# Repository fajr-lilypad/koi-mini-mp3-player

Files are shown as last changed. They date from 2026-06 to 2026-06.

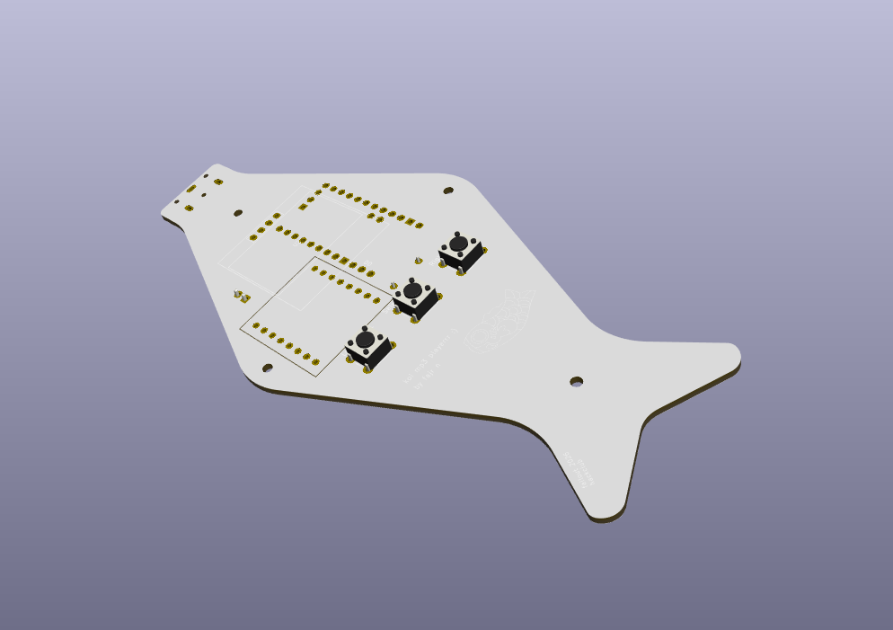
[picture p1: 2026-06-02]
PCB/ScreenshotPCB_3DViewer_SideB.png

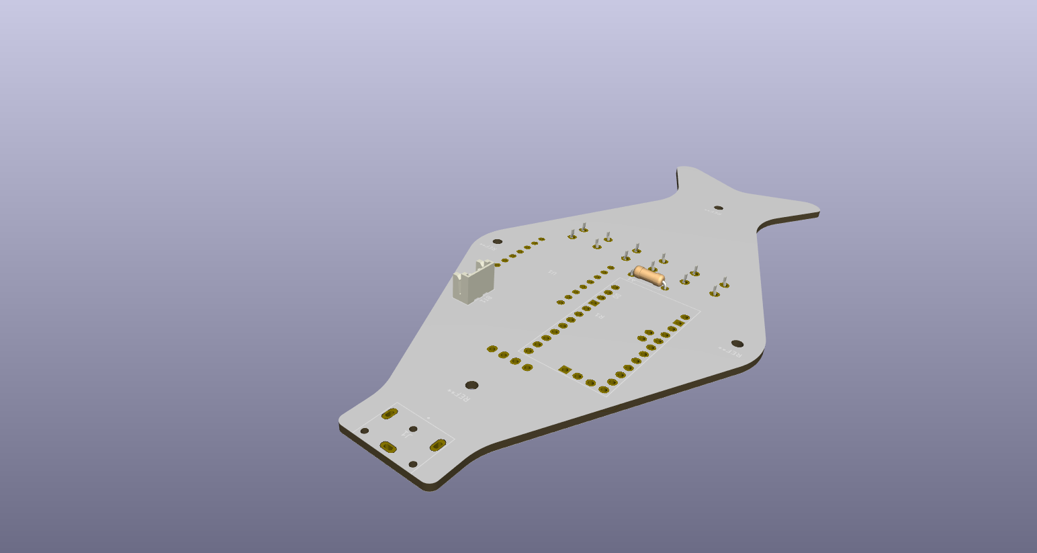
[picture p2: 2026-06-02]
PCB/PCBScreenshot_3DViewer.png

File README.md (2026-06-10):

# Koi Mini Mp3 Player!
A friendly fish shaped Mp3 player, that sings a tune to cheer you up :)



I came up with this idea when I came across creaters making projects that incorporated audio, and since I don't have as much experience with electrical projects, I thought this would be a fun and educational endeavor. When thinking over what cute designs and shapes I could make this, I became inspired by the friendly koi currency mascot used by hackclub's **fallout** program! I made this project because I wanted to learn more about complex electronics projects, as well as creating something practical that I can use day to day, and I listen to music all the time! And thus, here we are. This will be a helpful and cute tool for listening to tunes on the go, especially when I dont have access to spotify at school hahahaha (i'm **not** crying) (｡T ω T｡)

Some special things I did include making a more complex pcb than I have ever worked with before, along with not following a guided electronics project, so I kinda had to be more independent with troubleshooting and just making decsiions about my own project. In order to use this device, navigate through with a simple screen display to play songs stored on a micro sd card, along using right, left, and select buttons! It very simple to use and assemble. 

# CAD ScreenShots



<table>
  <tr>
    <td>
    
    </td>
    <td>
      
    </td>
    <td>
      
    </td>
  </tr>
</table>

CAD Notes:
- Arduino model in CAD does not match up with footrpint or irl, trust the footprint. it was just the best 3d model I could find.
- This CAD took surprisingly long! It was difficult for me to create a case that fufilled all my criteria, including space, aesthetics, and easy access to the pcb for simple troubleshooting. I ended up going with this design, but not after making several rough drafts of potential cases. I'm happy with this one, as it includes snap fit joints, a hole for the headphone jack, and is overall super cute :)
- The most difficult parts of this was the parts that nobody notices, mounting holes lol. took a while to align, but I'm sure most people are more efficient at cad than i am!

# PCB ScreenShots

<table>
  <tr>
    <td rowspan="2">
      
    </td>
    <td>
      
    </td>
  </tr>
  <tr>
    <td>
      
    </td>
  </tr>
</table>

PCB Notes:
- The PCB took me a **while**. It took 6 versions to come up with the final draft. The biggest difficulty was deciding a layout that would be easy to work with and troubleshoot, along with research into which components I should use. I had to learn how to do a lot of new things in KiCad, including making my own symbols!
- For structure, I created a blank PCB with the same shape attached to the bottom of the real pcb with brass standoffs. I found in my research that this is common when creating mp3 players, along with custom PCBs in general. After running into trouble with mounting, I scrapped that idea. Now, the there is just one pcb secured with standoffs.

## Schematic ScreenShot



# Zine !!



# Build Guide

Assembly for this Fish MP3 Player isn't too complicated. To start off, once components have arrived, be sure that your code is ready. When assembling components, I plan on starting out with a breadboard to test firmware before soldering, and be sure to secure the bottom blank pcb with standoffs. In the meantime, get the 3d printer started on the case top, bottom, and fins! The snap fit joints should make the case easy to work with, so it isnt hard to access the pcb.

## Firmware

I customized code for the display from Pcbcupid soundpod and used a butmap converter to display the images! Download whatever songs you'd like to be played on a micro sd card, and program to navigate through the files with the Pcbcupid reference mentioned earlier.

## BOM

| Item | Purpose | Price | Source | Link |
|---|---|---|---|---|
| Arduino Pro Mini | Microcontroller | $1.66 | AliExpress | https://www.aliexpress.us/item/3256809225264759.html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.. |
| DFPlayer Mini | Audio Module | $0.73 | AliExpress | https://www.aliexpress.us/item/3256806817772564.html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 |
| 1.3 in OLED | Display Screen | $0.99 | AliExpress | https://www.aliexpress.us/item/3256809997650807.html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 |
| TRS Female Headphone Jack | Audio output | $1.15 | DigiKey | https://shorturl.at/xDjAV | 
| 3.7 V Battery | Power | $4.18 | AliExpress | https://www.aliexpress.us/item/3256808681500642.html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 |
| 2 pin JST Battery Connector | Battery Connector | $3.90 | Aliexpress| https://shorturl.at/0xLe1 |
| Micro SD Card | Store songs | $1.13 | AliExpress | https://www.aliexpress.com/ssr/300000512/BundleDeals2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 |
| Micro Push Buttons | Inputs | $0.33 | Same Sky | https://www.sameskydevices.com/product/switches/tactile-switches/ts24-62-14-bl-250-smt-tr-67 |
| Custom Tactile Buttons | Comfort | $0 | 3D Printed |
| Custom Koi Case | Aesthetics | $0 | 3D Printed |
| Breadboard | testing | $0.55 | AliExpress | https://shorturl.at/7gDRe |
| Custom PCB | PCB | $5.30 | JLCPCB |
| Brass PCB standoffs | Supports structure | $0.99 | AliExpress | https://shorturl.at/dPENK |
| Soldering Iron | Assembly | $0 | Owned |
| 3D Printer | Case Manufacturing | $0 | Owned |
| Wired Headphones | Audio Output | $0 | Owned |
|  |  |  |  | **Subtotal: $20.91 USD**  |

## Notes and Acknowledgments
- Thank you to **Hackclub** and the **Fallout team** for making this project possible! It's because of you that I was inspired and able to make this project!
- Thank you to the user Digiicam for helpful inspo for wiring and components!
- Thank you to Pcbcupid for simple customizable firmware!

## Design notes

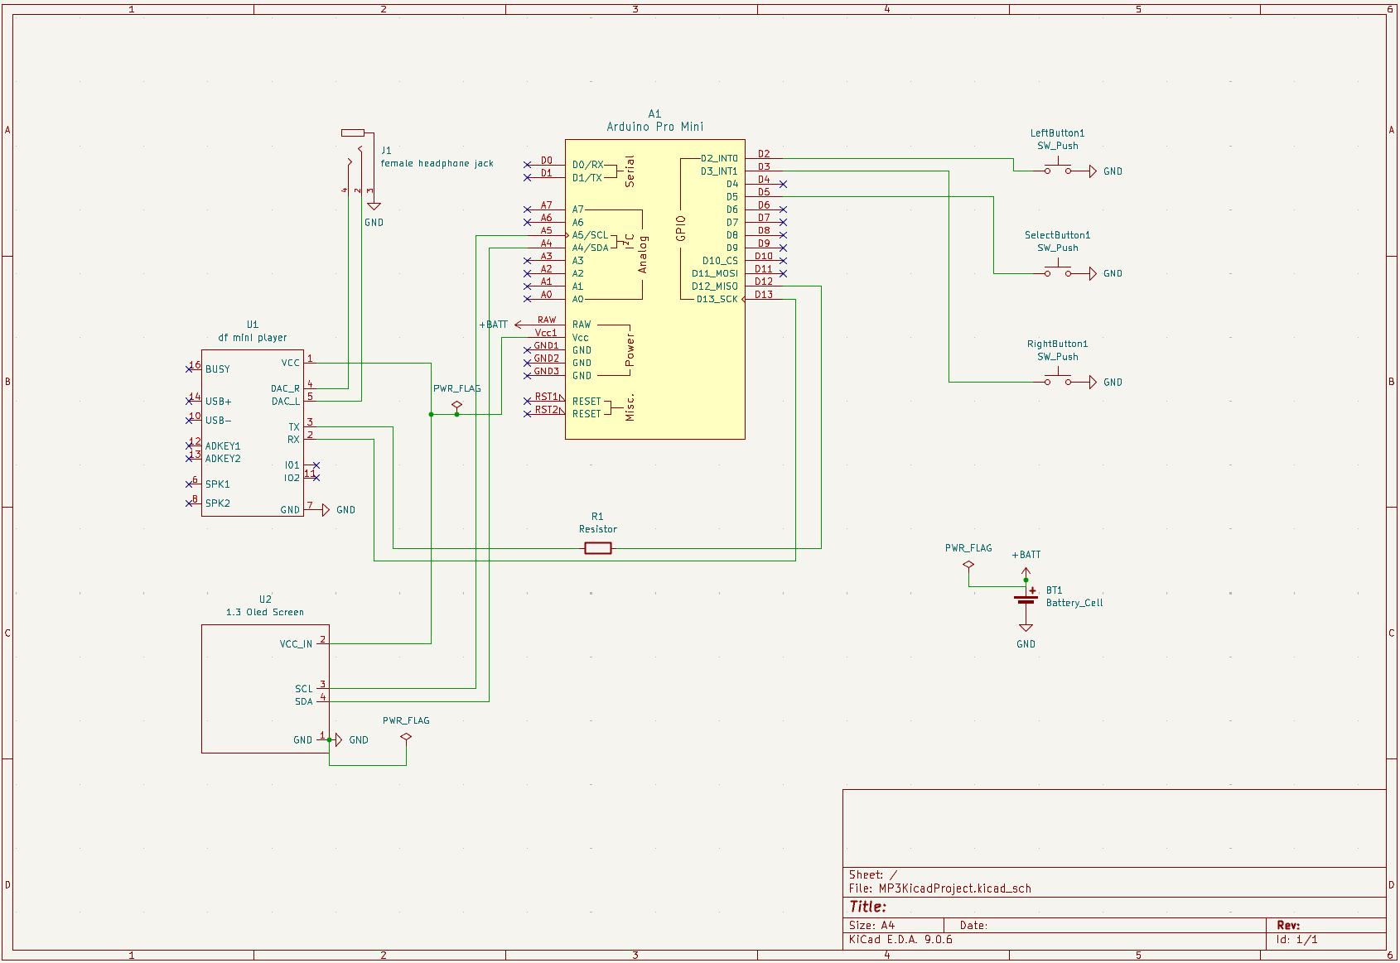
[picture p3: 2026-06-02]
Schematic/Screenshot 2026-06-01 223904.png

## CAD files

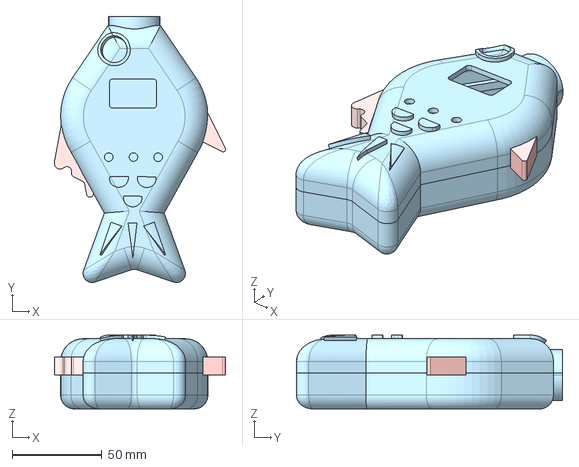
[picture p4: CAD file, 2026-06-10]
CAD/Case/Koi Case assembly.step
95.5 x 148.1 x 41.1 mm

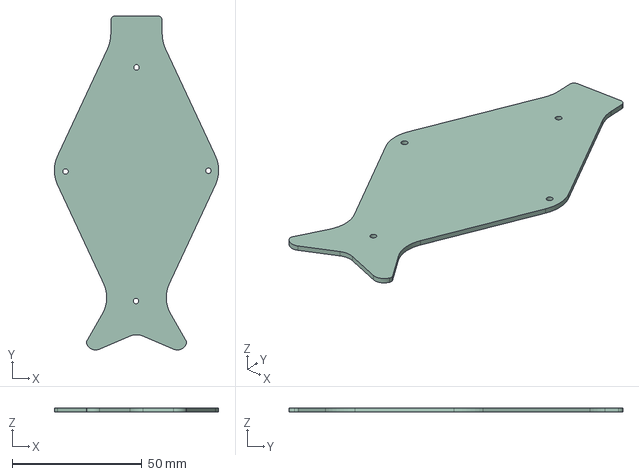
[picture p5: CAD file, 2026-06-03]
CAD/PCB Cad/Bottom Blank PCB.step
63.3 x 128.6 x 1.51 mm

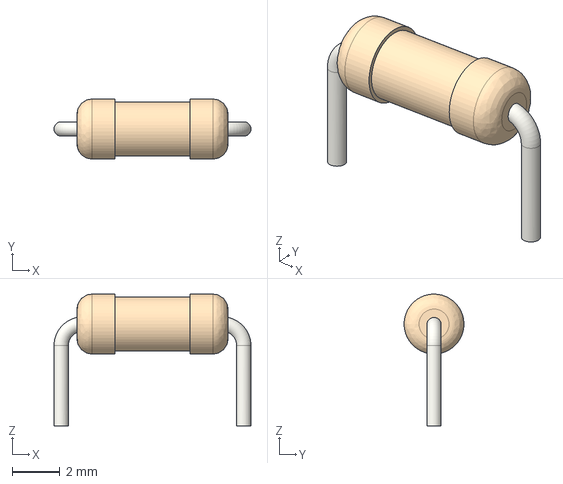
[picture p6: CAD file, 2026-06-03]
CAD/PCB Cad/Electronics/Resisitor.step
8.22 x 2.50 x 5.50 mm

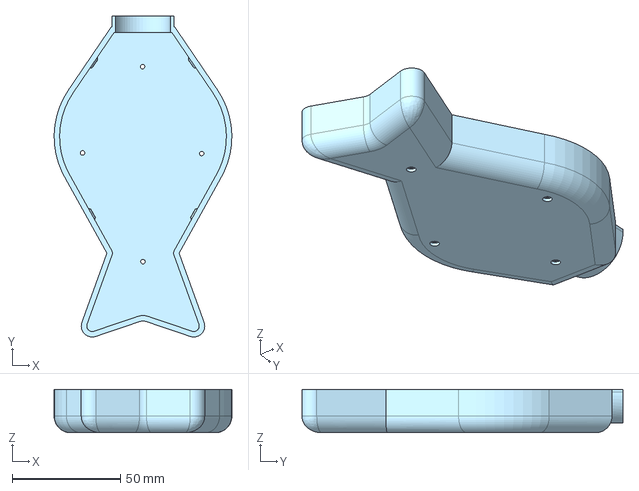
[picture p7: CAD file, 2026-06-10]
CAD/Case/koi case bottom.step
82.0 x 148.1 x 20.1 mm

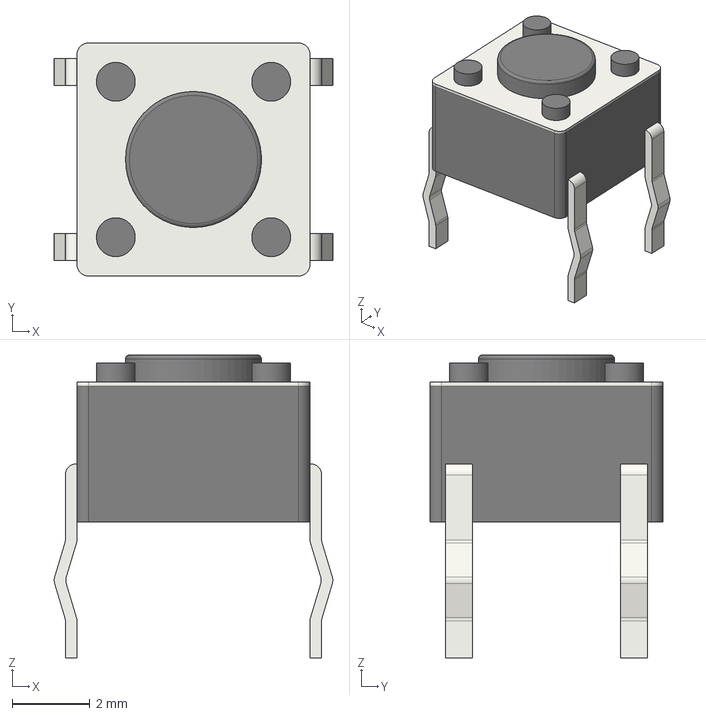
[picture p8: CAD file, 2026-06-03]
CAD/PCB Cad/Electronics/SW_PUSH_6mm Button.step
7.17 x 6.00 x 7.80 mm

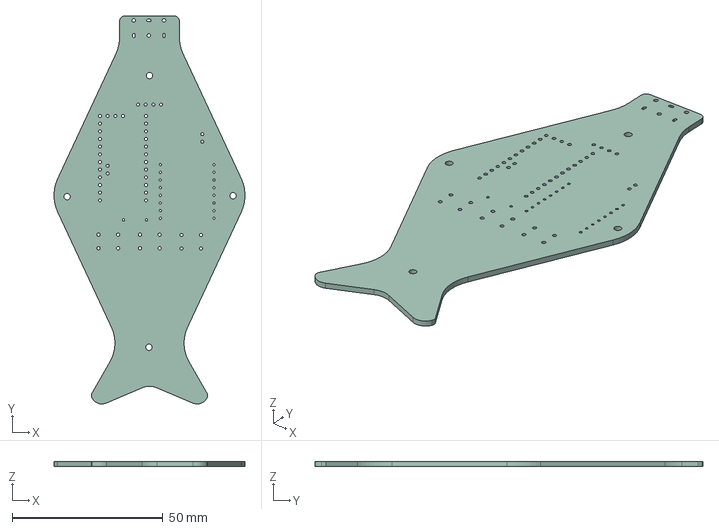
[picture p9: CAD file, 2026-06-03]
CAD/PCB Cad/MP3 PCB.step
63.3 x 128.6 x 1.51 mm

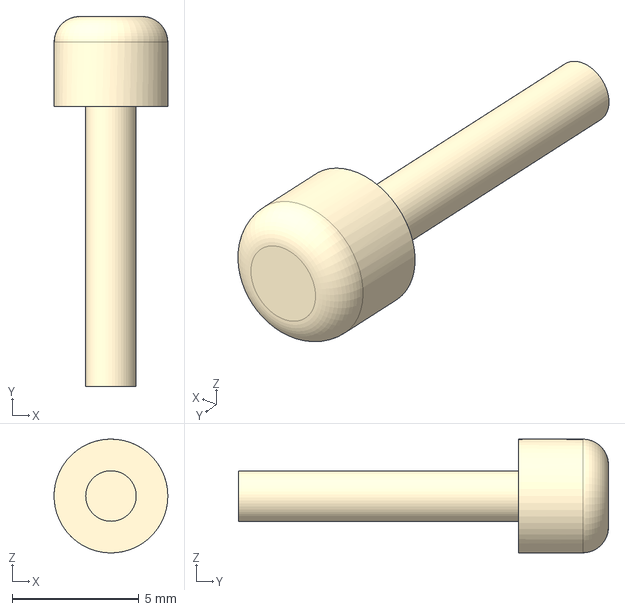
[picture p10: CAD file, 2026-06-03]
CAD/Case/Tactile Buttons.step
4.49 x 14.6 x 4.49 mm

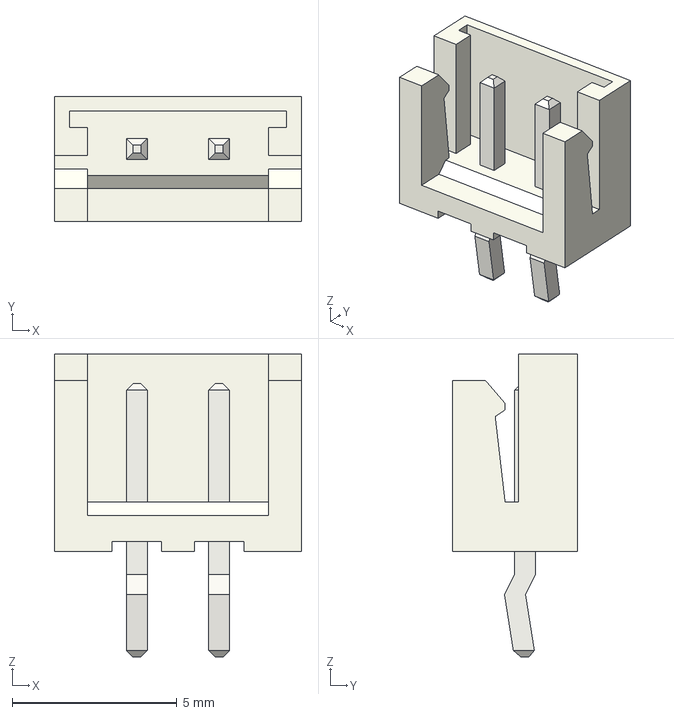
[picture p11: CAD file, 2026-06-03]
CAD/PCB Cad/Electronics/JST 2.50mm_Vertical Battery Connector.step
7.50 x 3.80 x 9.20 mm

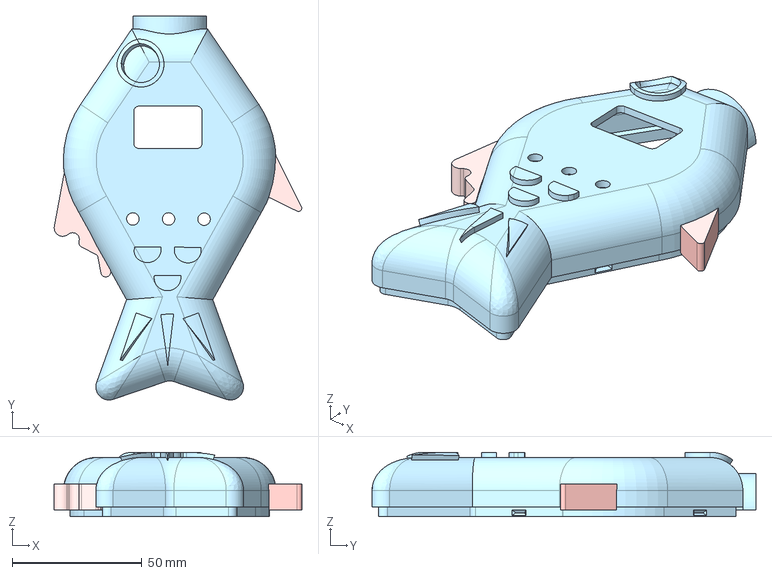
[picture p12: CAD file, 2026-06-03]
CAD/Case/Koi Case Top.step
95.5 x 148.1 x 24.9 mm

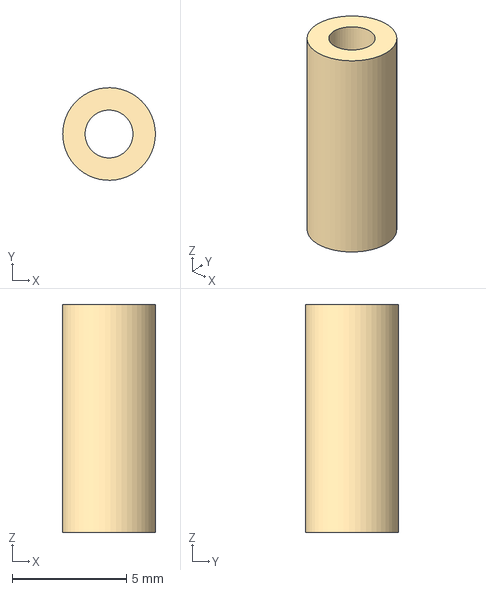
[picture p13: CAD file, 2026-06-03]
CAD/PCB Cad/Electronics/Brass 10mm standoff.step
4.06 x 4.06 x 10.0 mm

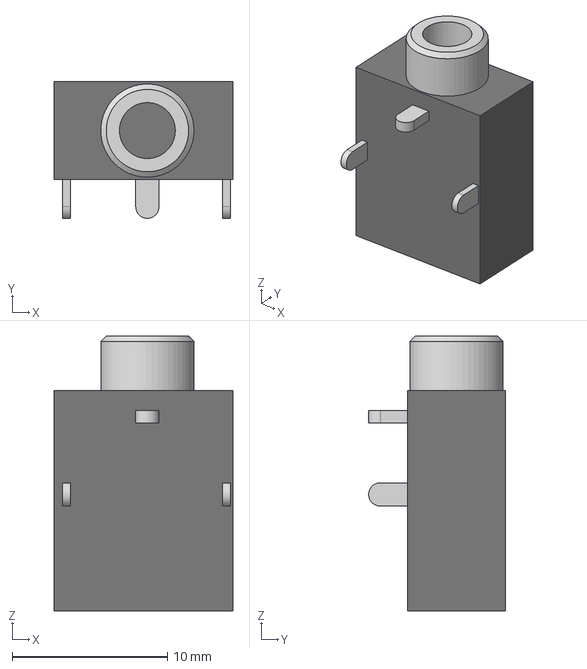
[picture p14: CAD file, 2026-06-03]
CAD/PCB Cad/Electronics/Headphone Jack 3.5 mm TRS female.step
11.5 x 8.80 x 17.7 mm

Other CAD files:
CAD/PCB Cad/Electronics/Arduino Pro Mini.step
CAD/Koi Mp3 Full Assembly.f3z

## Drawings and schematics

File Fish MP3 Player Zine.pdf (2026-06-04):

# fifisshh mmpp33 ppllaayyeerr

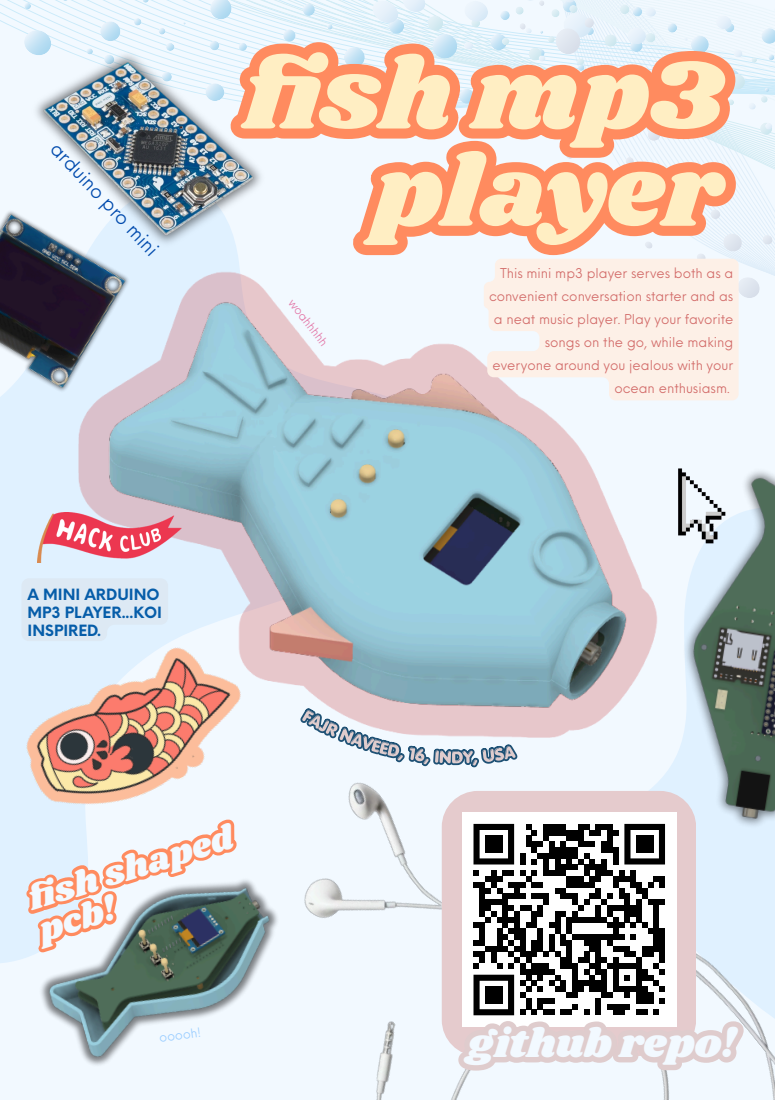
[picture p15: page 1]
fish mp3 player; woahhhhh; A MINI ARDUINO MP3 PLAYER...KOI INSPIRED.; fish shaped fish shaped pcb! pcb!; sh shaped pcb!; ocean enthusiasm.; ooooh!; ggiitthhuubb rreeppoo!!

arduino pro mini

This mini mp3 player serves both as a
convenient conversation starter and as
a neat music player. Play your favorite
songs on the go, while making
everyone around you jealous with your

FAJR NAVEED, 16, INDY, USA

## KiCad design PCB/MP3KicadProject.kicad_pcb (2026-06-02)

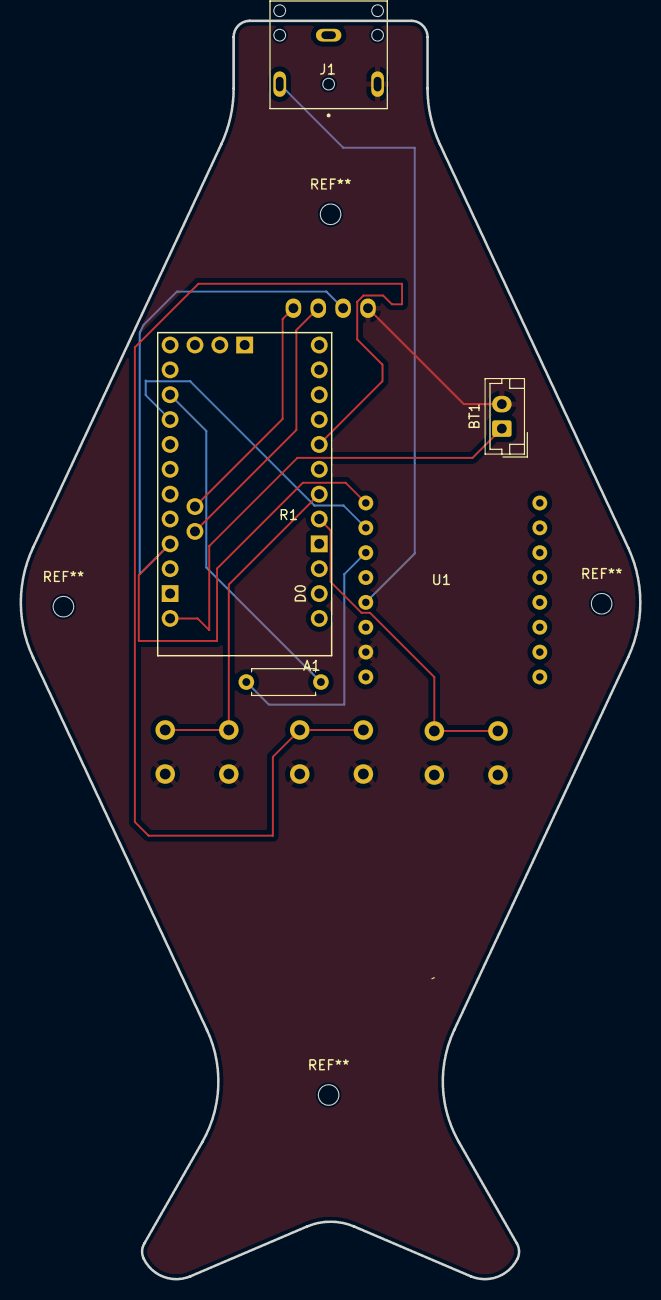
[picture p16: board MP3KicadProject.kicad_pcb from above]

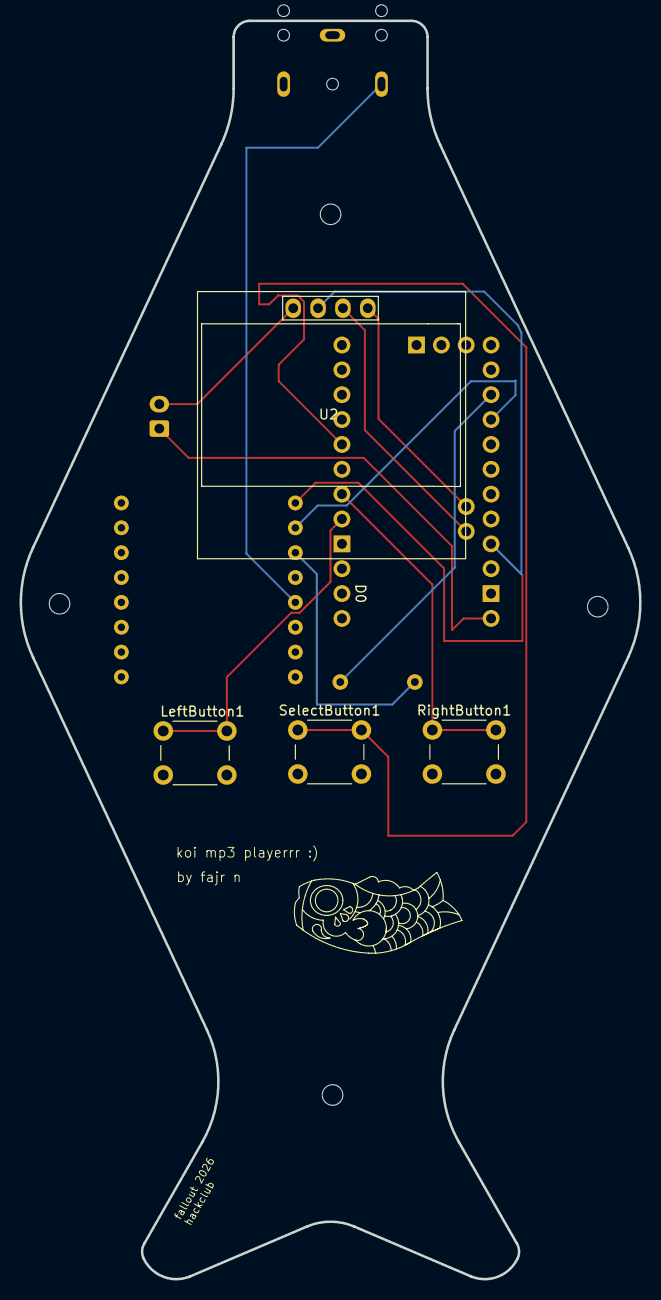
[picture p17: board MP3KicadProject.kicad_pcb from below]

Board: 2 copper layers, 63.3 x 128.6 mm, 9 parts (4 on the bottom side), 12 nets.

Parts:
A1: Arduino Pro Mini; Clone_Pro_Mini_Socket_NoSPH
BT1: Battery_Cell; JST_EH_B2B-EH-A_1x02_P2.50mm_Vertical
J1: female headphone jack; CUI_SJ1-3523N
LeftButton1: SW_Push; SW_PUSH_6mm
R1: Resistor; R_Axial_DIN0207_L6.3mm_D2.5mm_P7.62mm_Horizontal
RightButton1: SW_Push; SW_PUSH_6mm
SelectButton1: SW_Push; SW_PUSH_6mm
U1: df mini player; DFPlayer
U2: 1.3 Oled Screen; 128x64OLED

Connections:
+BATT: A1.RAW, BT1.1 (+)
GND: BT1.2 (-), J1.3, LeftButton1.2, RightButton1.2, SelectButton1.2, U1.7 (GND), U2.1 (GND)
unnamed: A1.A4 (A4/SDA), U2.4 (SDA)
unnamed: A1.A5 (A5/SCL), U2.3 (SCL)
unnamed: A1.D2 (D2_INT0), LeftButton1.1
unnamed: A1.D3 (D3_INT1), RightButton1.1
unnamed: A1.D12 (D12_MISO), R1.2
unnamed: A1.D13 (D13_SCK), U1.2 (RX)
unnamed: A1.D5, SelectButton1.1
unnamed: A1.Vcc1 (Vcc), U1.1 (VCC), U2.2 (VCC_IN)
unnamed: J1.2, U1.5 (DAC_L)
unnamed: R1.1, U1.3 (TX)

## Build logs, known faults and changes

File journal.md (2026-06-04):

## Progress Journal!

This is just so that you can view my progress through this project. I definetly ran into A LOT of problems. Namely:

  ## May 29th, 2026, 2 PM

Today I mostly did research, as well as mapping out a schematic. After watching tons of youtube videos (off camera obv), I think I have a good foundation of which parts to use. I also found videos on how to create a schematic in kicad, and how to get various arduino librarys. That was a lot of digging :p Additionally, i made some custom symbols for the first time in kicad! Overall, today was def a learning day rather than a project grind day. Next time i will prob add some leds to the schematic or even get to CAD on the case!!



## May 29th, 2026, 4 PM

I created the top layer for my pcb! this was my first time attempting a pcb stack, and it was... a struggle. I looked through a bunch of references for loads of stacked pcb projects, so making the next two shouldn't be as difficult as it was this time. I can't wait to cad and do something i'm actually good at ദ്ദി╥ ᴗ ╥)



## May 29th, 2026, 7 PM

So uh. I kinda redid the pcb.

I thought it out a whole lot and kinda made some adjustments to my original stacked pcb idea, and with that, I also brainstormed some fun case ideas like a fish shaped one, to where i thought:
"why not make a koi mp3 player?"
and here we are folks. I attempted to draw up a sketch in Figma and import it, but that ended up a waste, so i just imported a dxf i made on fusion. I got a basic pcb layout done, but there will most def be some changes. i am excited to finish this pcb up!



## May 30th, 2026, 12:45 PM

Continued to work on pcb, but ran drc and found a bunch of errors :( I have to go somewhere but will continue to work on fixing those up when i get back!



## May 30th, 2026, 6 PM

finished pcb!!
Yaaaayyy!! That was a whirl! I also made a top and bottom blank pcbs that i may secure with standoffs (ill test how it looks in CAD, if it sucks ill just make a regular case). anyhow, im gonna triple check stuff before getting the gerbers, and then, onto cad !!!



## May 31st, 2026, 9 PM

I got started on cad! And thats how i found out that i had some pcb layout problems (╥﹏╥). Those were fairly simple, and it took me a while but i scavenged and found all the step files i needed. until i realized...
MY ARDUINO FOOTPRINT WAS WRONG
so i tried to find a good one online yk one with CORRECT PIN ALIGNMENT, but that didnt work out. not to mention my computer was bugging out. i shall continue the search tomorrow, bc my brain hurts rn.



## June 1st, 2026, 8 PM

PCB is DONE!! Actually, this time the pcb is really done, i am not making anymore edits!! This is it folks!

also, basic assembly of all electronic components has been completed in cad!! yippee! only ran into the problem of not finding a sufficient arduino 3d model that could match with my footprint, but, alas, I made do. i also made some cute tactile buttons, and i am going to get to cadding a beautiful koi case very soon ;)



## June 2nd, 2026, 4 PM

Finally, got to cadding the case!!
I'm gonna be honest, it was harder than I thought it would be. First, I didnt even make it the right size, and then I had to deal with the fact that it looked more like a rocket ship than a fish. After tons of editing, I've gotten to a place where I am happy with (as a 1st draft). I plan to pretty it up, by adding a hinge and embossing scales and other details. Lets see how this goes!



## June 2nd, 2026, 6 PM

I continued to CAD and created a new version of the case that I think I'm a lot happier with! I also switched some stuff around aesthetics wise. I think I can get to submitting this very soon!



## June 3rd, 2026, 6 PM

So, CAD is officially finished up! Now, I'm finalizing everything in my repo and also plan on getting started on my zine! This has been really awesome, and I've learned a lot!



## June 4th, 2026, 1 PM

Today, I polished up CAD and firmware. I finished up small details in the case (snap fit joints, embossed details) and started on software, where I downloaded soundpod code and customized it so that my display would flash a koi fish image! At first, I was confused on how I would put a png on my OLED, so I used a bitmap converter that converted my image into arduino binary code. I also got a lot of work done with my READme, added links to my BOM, did some rendering, and just made it look pretty overall. Next stop, zine!




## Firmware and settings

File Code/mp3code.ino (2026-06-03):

#include <Arduino.h>
#include <SoftwareSerial.h>
#include <DFRobotDFPlayerMini.h>
#include <U8g2lib.h>
#include <Wire.h>
#include <EEPROM.h>
#include "OneButton.h"

// 65 - Audio Settings Icon
// 66 - Flash screen Spectrum 
// 67 - Battery empty 
// 68 - Battery full 
// 69 - left adjustment button
// 70 - right adjustment button
// 71 - back button 
// 72 - pause button
// 73 - play button
// 74 - previous button
// 75 - Next button
// 76 - Music Icon
// 77 - volume full
// 78 - volume half 
// 79 - volume low

extern const uint8_t soundpod_icon_pack_font[350] U8G2_FONT_SECTION("soundpod_icon_pack_font") = 
  "\17\0\4\4\5\6\3\3\7\34 \0\0\16\0\16\0\0\0\0\0\1AA&p\341\241\22\64\214\310" 
  "!BE\210\11\24\206\210 !D\4\11!\42H\10\21ABD\10\25\42TL\320 \0BZ\34" 
  "$\301\17\202<H\362 \311\203$\17\202\20y\20\204\310\203 D\36\4!\362 \10QH\210BB"
  "\24\22\42\204\210\42D\24!\242\10\21E\210(BD\21\42\212\20\321\220\20\205\204($D!!\12"
  "\11\221\7A\210<\10B\344A\20\42\17\222<H\362 \311\203$\10\0C\17\310`\221p\42T\210"
  "PS\205\70\1\0D\14\310`\221p\342\304\3\24'\0E\12\303x\221\22\2\205\220\0F\13\303p" 
  "\221\20D\4\212 \0G\16\250\240\221\21(\304\220\21fH\211\1H\12\214\261\241@\10\377G\4I"
  "\24\213\261\241\20t`\261CI\36<\10r\250\330\300\240\0J\14\307`\221 h\14\11k\10\5K" 
  "\15\307`\221\20\210\214\11\23d\6\11L\35\20\42\241yj\21G\304\4\11\24$P\220@A\242\12"
  "\11\62Q\210W$\314\222\5M\24\10!\221\23L\204\10\42&B\224\10QD\12A\201\0N\16\6"
  ")\221\23H\10\25\25\211\12\2\0O\13\4\61\221\23\344\301\20\61\1\0\0\0\4\377\377\0";

const uint8_t leftButtonPin = 3;
const uint8_t selectionButtonPin = 5;
const uint8_t rightButtonPin = 2;

volatile uint8_t sMenuSelection = 2;
volatile uint8_t selection = 1;
volatile bool updateScreen = true;

// Variables
uint8_t filecounts;                     // total number of files in current folder
uint8_t foldercounts;                   // total number of folders on sd-card

uint8_t volume = 20;                    // current volume (0 .. 30)
uint8_t folder = 1;                     // current sd-card folder
uint8_t file   = 1;                     // curent file in current folder
uint8_t eq = 0;

uint8_t batteryLevel = 0;
uint8_t mins = 0;
unsigned long lastBatteryRead = 0;

boolean playing = false;
boolean inSideMenuSelection = true;

OneButton PreviousBTN(leftButtonPin, true);
OneButton PlayBTN(selectionButtonPin, true);
OneButton NextBTN(rightButtonPin, true);

SoftwareSerial customSoftwareSerial(12,13);
DFRobotDFPlayerMini myDFPlayer;

U8G2_SH1106_128X64_NONAME_1_HW_I2C u8g2(U8G2_R0, /* reset=*/ U8X8_PIN_NONE);

void setup(void) {
  
  //being hardware serial for debugging
  Serial.begin(9600);

 // Initializing u8g2 library
  u8g2.begin();  
  u8g2.firstPage(); 
  do{
    
    flashPage();    
  
  }while(u8g2.nextPage());
  
  PreviousBTN.attachClick(preivousButtonClicked);
  PlayBTN.attachClick(playButtonClicked);
  NextBTN.attachClick(nextButtonClicked);
  
  PreviousBTN.setDebounceMs(50);
  PlayBTN.setDebounceMs(50);
  NextBTN.setDebounceMs(50);

  //Initializing software serial
  customSoftwareSerial.begin(9600);

  if (!myDFPlayer.begin(customSoftwareSerial)) {  //Use softwareSerial to communicate with mp3.
    Serial.println(F("Please insert the SD card!")); 

  }        Serial.println(foldercounts); 

  volume = EEPROM.read(0);
  if(volume > 30)
  volume = 30;
  
  eq     = EEPROM.read(1);
  if(eq > 5)
  eq = 5;
  
  file   = EEPROM.read(2);
  if(file >= 255)
  file = 1;
  
  delay(1000);
  myDFPlayer.volume(volume);  //Set volume value. From 0 to 30
  delay(500);
  foldercounts = myDFPlayer.readFolderCounts();
  //startFolderPlay();
   //myDFPlayer.playFolder(folder, 1);
//  
}

void loop() {
  

  //Check constantly for button inputs
  PreviousBTN.tick();
  PlayBTN.tick();
  NextBTN.tick();
  //Update the display as required 
  updateDisplay();
  updateDFplayer();

}

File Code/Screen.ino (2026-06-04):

void updateDisplay() {
  //Updating the dispaly
  if (updateScreen) {
    u8g2.firstPage();
    do {
      int ch = (sMenuSelection);
      switch (ch) {
        case 1:
          player();
          break;
        case 2:
          settings();
          break;
        default:
          Serial.println(F("Default Screen"));
      }
      updateScreen = false;
    } while (u8g2.nextPage());
  }
}

void settings() {
  sideMenu();
  topMenu();
  u8g2.setFont(u8g2_font_fancypixels_tr);

  u8g2.setCursor(47, 17);
  u8g2.print(F("Settings :3"));

  u8g2.setFontMode(0);

  u8g2.setFont(u8g2_font_fancypixels_tr);
  u8g2.setCursor(47, 40);
  u8g2.print(F("Volume:"));
  if (selection == 1 && !inSideMenuSelection) {
    u8g2.setFont(soundpod_icon_pack_font);
    if (volume > 0)
      u8g2.drawGlyph(85, 40, 69); // drawing left ajustment button next to the volume
    if (volume < 30) {
      if (volume < 10)
        u8g2.drawGlyph(100, 40, 70); // drawing right ajustment button next to the volume for single digit volume
      else
        u8g2.drawGlyph(105, 40, 70);  // drawing right ajustment button next to the volume for double digit volume
    }
  }
  u8g2.setFont(u8g2_font_fancypixels_tr);
  u8g2.setCursor(95, 40);
  u8g2.print(volume);
  u8g2.setDrawColor(1);

  u8g2.setCursor(47, 60);
  u8g2.print(F("EQ"));
  if (selection == 2 && !inSideMenuSelection) {
    u8g2.setFont(soundpod_icon_pack_font);
    if (eq > 0)
      u8g2.drawGlyph(85, 60, 69); // drawing left ajustment button next to the volume
    if (eq < 5)
      u8g2.drawGlyph(100, 60, 70); // drawing right ajustment button next to the volume
  }
  u8g2.setFont(u8g2_font_fancypixels_tr);
  u8g2.setCursor(95, 60);
  u8g2.print(eq);
  u8g2.setDrawColor(1);

  if (selection == 4 && !inSideMenuSelection) {
    u8g2.setDrawColor(0);
  }
  u8g2.setFont(soundpod_icon_pack_font);
  u8g2.drawGlyph(120, 60, 71); // drawing back button to the bottom off the screen
  u8g2.setDrawColor(1);
}

void flashPage() {
// Bitmap generated for 115x128 display
// Image: koifish
// Method: Ordered (Bayer)
// Format: 115x128, 1 bit/pixel, LSB first

#ifndef KOIFISH_BITMAP_H
#define KOIFISH_BITMAP_H

// Width: 115
// Height: 128

static const unsigned char PROGMEM koifish_bitmap[1920] = {
  0x00,0x00,0x00,0x00,0x00,0x00,0x00,0x00,0x00,0x00,0x00,0x00,0x00,0x00,0x00,
  0x00,0x00,0x00,0x00,0x00,0x00,0x00,0x00,0x00,0x00,0x00,0x00,0x00,0x00,0x00,
  0x00,0x00,0x00,0x00,0x00,0x00,0x00,0x00,0x00,0x00,0x00,0x00,0x00,0x00,0x00,
  0x11,0x11,0x11,0x11,0x11,0x11,0x11,0x11,0x11,0x11,0x11,0x11,0x11,0x11,0x01,
  0x00,0x00,0x00,0x00,0x00,0x00,0x00,0x00,0x00,0x00,0x00,0x00,0x00,0x00,0x00,
  0x00,0x00,0x00,0x00,0x00,0x00,0x00,0x00,0x00,0x00,0x00,0x00,0x00,0x00,0x00,
  0x00,0x00,0x00,0x00,0x00,0x00,0x00,0x00,0x00,0x00,0x00,0x00,0x00,0x00,0x00,
  0x11,0x11,0x11,0x11,0x11,0x11,0x11,0x11,0x11,0x11,0x11,0x11,0x11,0x11,0x01,
  0x00,0x00,0x00,0x00,0x00,0x00,0x00,0x00,0x00,0x00,0x00,0x00,0x00,0x00,0x00,
  0x00,0x00,0x00,0x00,0x00,0x00,0x00,0x00,0x00,0x00,0x00,0x00,0x00,0x00,0x00,
  0x00,0x00,0x00,0x00,0x00,0x00,0x00,0x00,0x00,0x00,0x00,0x00,0x00,0x00,0x00,
  0x11,0x11,0x11,0x11,0x11,0x11,0x11,0x11,0x11,0x11,0x11,0x11,0x11,0x11,0x01,
  0x00,0x00,0x00,0x00,0x00,0x00,0x00,0x00,0x00,0x00,0x00,0x00,0x00,0x00,0x00,
  0x00,0x00,0x00,0x00,0x00,0x00,0x00,0x00,0x00,0x00,0x00,0x00,0x00,0x00,0x00,
  0x00,0x00,0x00,0x00,0x00,0x00,0x00,0x00,0x00,0x00,0x00,0x00,0x00,0x00,0x00,
  0x11,0x11,0x11,0x11,0x11,0x11,0x11,0x11,0x11,0x11,0x11,0x11,0x11,0x11,0x01,
  0x00,0x00,0x00,0x00,0x00,0x00,0x00,0x00,0x00,0x00,0x00,0x00,0x00,0x00,0x00,
  0x00,0x00,0x00,0x00,0x00,0x00,0x00,0x00,0x00,0x00,0x00,0x00,0x00,0x00,0x00,
  0x00,0x00,0x00,0x00,0x00,0x00,0x00,0x00,0x00,0x00,0x00,0x00,0x00,0x00,0x00,
  0x11,0x11,0x11,0x11,0x11,0x11,0x11,0x11,0x11,0x11,0x11,0x11,0x11,0x11,0x01,
  0x00,0x00,0x00,0x00,0x00,0x00,0x00,0x00,0x00,0x00,0x00,0x00,0x00,0x00,0x00,
  0x00,0x00,0x00,0x00,0x00,0x00,0x00,0x00,0x00,0x00,0x00,0x00,0x00,0x00,0x00,
  0x00,0x00,0x00,0x00,0x00,0x00,0x00,0x00,0x00,0x00,0x00,0x00,0x00,0x00,0x00,
  0x11,0x11,0x11,0x11,0x11,0x11,0x11,0x11,0x11,0x11,0x11,0x11,0x11,0x11,0x01,
  0x00,0x00,0x00,0x00,0x00,0x00,0x00,0x00,0x00,0x00,0x00,0x00,0x00,0x00,0x00,
  0x00,0x00,0x00,0x00,0x00,0x00,0x00,0x00,0x00,0x00,0x00,0x00,0x00,0x00,0x00,
  0x00,0x00,0x00,0x00,0x00,0x00,0x00,0x00,0x00,0x00,0x00,0x00,0x00,0x00,0x00,
  0x11,0x11,0x11,0x11,0x11,0x11,0x11,0x11,0x11,0x11,0x11,0x11,0x11,0x11,0x01,
  0x00,0x00,0x00,0x00,0x00,0x00,0x00,0x00,0x00,0x00,0x00,0x00,0x00,0x00,0x00,
  0x00,0x00,0x00,0x00,0x00,0x00,0x00,0x00,0x00,0x00,0x00,0x00,0x00,0x00,0x00,
  0x00,0x00,0x00,0x00,0x00,0x00,0x00,0x00,0x00,0x00,0x00,0x00,0x00,0x00,0x00,
  0x11,0x11,0x11,0x11,0x11,0x11,0x11,0x11,0x11,0x11,0x11,0x11,0x11,0x11,0x01,
  0x00,0x00,0x00,0x00,0x00,0x00,0x00,0x00,0x00,0x00,0x00,0x00,0x00,0x00,0x00,
  0x00,0x00,0x00,0x00,0x00,0x00,0x00,0x00,0x00,0x00,0x00,0x00,0x00,0x00,0x00,
  0x00,0x00,0x00,0x00,0x00,0x00,0x00,0x00,0x00,0x00,0x00,0x00,0x00,0x00,0x00,
  0x11,0x11,0x11,0x11,0x11,0x11,0x11,0x11,0x11,0x11,0x11,0x11,0x11,0x11,0x01,
  0x00,0x00,0x00,0x00,0x00,0x00,0x00,0x00,0x00,0x00,0x00,0x00,0x00,0x00,0x00,
  0x00,0x00,0x00,0x00,0x00,0x00,0x00,0x00,0x00,0x00,0x00,0x00,0x00,0x00,0x00,
  0x00,0x00,0x00,0x00,0x00,0x00,0x00,0x00,0x00,0x00,0x00,0x00,0x00,0x00,0x00,
  0x11,0x11,0x11,0x11,0x11,0x11,0x11,0x11,0x11,0x11,0x11,0x11,0x11,0x11,0x01,
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
};

#endif // KOIFISH_BITMAP_H


  u8g2.drawXBMP(19, -13, 84, 90, bunnyyyyy_bitmap); 

}

void topMenu() {
  u8g2.setFont(soundpod_icon_pack_font);

  if (volume >= 25)
    u8g2.drawGlyph(119, 9, 77);
  else if (volume > 10 && volume < 25)
    u8g2.drawGlyph(119, 9, 78);
  else if (volume <= 10)
    u8g2.drawGlyph(119, 9, 79);
  //
  //    u8g2.setFont(u8g2_font_glasstown_nbp_tf);
  //    u8g2.setCursor(25,9);
  //    u8g2.print(batteryLevel);
  //    u8g2.setCursor(35,9);
  //    u8g2.print("%");
}

void sideMenu() {
  const uint8_t menuListGlpy[2] = { 77, 64 };

  u8g2.setFontMode(0);

  //Audio player selection
  if (abs(sMenuSelection) == 1 && inSideMenuSelection) {
    u8g2.drawRBox(0, 12, 20, 21, 3);
    u8g2.setDrawColor(0);
  }

  //Audio player
  drawIcon(soundpod_icon_pack_font, 2, 30, 76);

  u8g2.setDrawColor(1);

  //setting Selection
  if (abs(sMenuSelection) == 2 && inSideMenuSelection) {
    u8g2.drawRBox(0, 33, 20, 19, 3);
    u8g2.setDrawColor(0);
  }
  //settings
 // Change the font to the symbols library
u8g2.setFont(u8g2_font_unifont_t_symbols); 

// Draw the star glyph (Unicode 0x2605 is a solid star)
u8g2.drawGlyph(2, 48, 0x2605); 

  u8g2.setDrawColor(1);
  //u8g2.drawLine(22, 0, 22, 68);
}
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

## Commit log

2026-05-29 Create BOM
2026-05-29 Update BOM
    headphones
2026-05-29 Create Schematic
2026-05-29 Create PCB
2026-05-29 Update BOM
2026-06-02 Rename Screenshot 2026-06-01 223904.png to PCB/Schematic.png
2026-06-02 Rename Screenshot 2026-06-01 223904.png to Schematic/Screenshot 2026-06-01 223904.png
2026-06-02 Rename Screenshot 2026-06-01 203631.png to PCBScreenshot_3DViewer.png
2026-06-03 Rename Koi Case Assembly.step to CAD/Case/Koi Case Assembly.step
    [Koi Case Assembly.step]
2026-06-03 Rename Koi Case Bottom.step to CAD/Case/Koi Case Bottom.step
    [Koi Case Bottom.step]
2026-06-03 Rename Koi Case Top.step to CAD/Case/Koi Case Top.step
    [Koi Case Top.step]
2026-06-03 Rename CAD/Mp3 PCB CAD Assembly.f3z to CAD/PCB Cad/Mp3 PCB CAD Assembly.f3z
    [Mp3 PCB CAD Assembly.f3z]
2026-06-03 Rename CAD/MP3 CAD PCB.step to CAD/PCB Cad/MP3 CAD PCB.step
    [MP3 CAD PCB.step]
2026-06-03 Rename MP3 CAD PCB.step to MP3 PCB.step
    [MP3 PCB.step]
2026-06-03 Rename Mp3 PCB CAD Assembly.f3z to Mp3 PCB Assembly.f3z
    [Mp3 PCB Assembly.f3z]
2026-06-03 Rename CAD/PCB Cad/SSD1306_OLED_Display(128x64).step to CAD/PCB Cad/Electronics/Adafruit SSD1306 1.3in OLED Display.step
    [Adafruit SSD1306 1.3in OLED Display.step, SSD1306_OLED_Display(128x64).step]
2026-06-03 Rename DFR0299--3DModel-STEP-56544.STEP to DF Player Mini.STEP
    [DF Player Mini.STEP, DFR0299--3DModel-STEP-56544.STEP]
2026-06-03 Rename Jack 3_5 mm TRS femaile.step to Headphone Jack 3.5 mm TRS female.step
    [Headphone Jack 3.5 mm TRS female.step]
2026-06-03 Rename ASSEMBLY.SLDASM to Arduino Pro Mini.step
    [Arduino Pro Mini.step]
